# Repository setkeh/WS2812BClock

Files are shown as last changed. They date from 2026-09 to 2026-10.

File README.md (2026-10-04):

# WS2812BClock

A wall clock built from 88 addressable SK6812 pixels driven by an ESP32: a
60-pixel ring showing hour, minute and second hands, and a four-digit
seven-segment display showing the time and date. Time comes from NTP, and
firmware updates arrive over HTTPS from a private update server.

Hardware geometry, the LED pinout and the printable soldering jigs live in
[`CAD/README.md`](CAD/README.md).

## Setting up on a new machine

Everything except three local secrets is in the repo.

### 1. Toolchain

The Nix flake pins ESP-IDF v5.5.2 and every toolchain:

```bash
direnv allow          # or: nix develop
idf.py --version      # ESP-IDF v5.5.2
```

For VS Code, install the **ESP-IDF** and **direnv** extensions. The flake
registers itself with the ESP-IDF extension automatically (see the shell hook
in `flake.nix`), so no manual "configure extension" step is needed.

### 2. The three things that are *not* in the repo

`sdkconfig` is gitignored, so each machine needs these set once:

| What | Where | Notes |
| --- | --- | --- |
| WiFi SSID and password | `idf.py menuconfig` → *WS2812B Clock Wifi* | Never put these in `sdkconfig.defaults` — that file is committed. |
| OTA server token | *WS2812B Clock OTA* → `OTA_AUTH_TOKEN` | Same reasoning. |
| Update server root CA | `components/ota/certs/server_ca.pem` | Copy the CA root there. `*.pem` is gitignored. |

Everything else has a sensible default in `sdkconfig.defaults` (4 MB flash, OTA
partition table, rollback, display pins and brightness, timezone).

### 3. Signing key

Images are signed, so **every build needs the key**. It lives in 1Password and
is fetched to tmpfs only for the duration of a build — see *Signing* below.

### 4. First flash

The partition table has two OTA slots, so a board coming from an older layout
must be erased once:

```bash
idf.py -p /dev/ttyUSB1 erase-flash
idf.py -p /dev/ttyUSB1 flash monitor
```

Afterwards, plain `flash` is enough.

## Configuration reference

All under `idf.py menuconfig`:

| Menu | Options |
| --- | --- |
| *WS2812B Clock Display* | Ring and digit GPIOs and pixel counts, day/night brightness for each, night window (default 19:00–06:00), rotation and `DISPLAY_CYCLE_SECONDS` |
| *WS2812B Clock Environment Sensor* | `DHT_ENABLE`, data GPIO, reading interval, retries |
| *WS2812B Clock Wifi* | SSID, password, `WIFI_MAXIMUM_RETRY`, `WIFI_POWER_SAVE` (off: modem sleep costs OTA throughput and log latency for power a mains-powered clock does not need) |
| *WS2812B Clock NTP* | Server (default `pool.ntp.org`), timezone (default Sydney), sync method |
| *WS2812B Clock OTA* | Base URL, model directory, token, certificate source, check-at-boot and interval, `OTA_PROGRESS_STEP_PCT`, `OTA_UPLOAD_COREDUMP`, `OTA_CRASH_URL` |
| *WS2812B Clock Remote Logging* | Collector host and UDP port, syslog APP-NAME, line length, queue depth, core dump reporting |
| *WS2812B Clock Debugger* | `DEBUG_BUILD` logging, status LED pin |
| *WS2812B Clock Fans* | Fan PWM pin |

Shipped defaults: ring on GPIO32 (60 px) at 5% day / 1% night, digits on
GPIO25 (28 px) at 50% day / 5% night. Brightness is worth tuning per build
once the diffusers are in — the values in a local `sdkconfig` win over these.

### Device identity

One value names the device, and everything follows it:

```
CONFIG_LWIP_LOCAL_HOSTNAME="hallway-clock"
```

It is not under any of this project's own menus — it lives in menuconfig under
**Component config → LWIP → Local netif hostname**, and defaults to
`espressif`, which is worth changing before a second device exists.

That one setting becomes the DHCP name on the network, the `host` label in
Loki, and the name a crash dump is filed under on the server. Nothing else
sets it: `logship` and the crash upload both read it back from the station
interface through `wifi_hostname()`, so they cannot disagree.

The distinction matters once there is more than one device, and it follows
RFC 5424:

| Field | Means | Set by | Example |
| --- | --- | --- | --- |
| HOSTNAME | which **device** | `CONFIG_LWIP_LOCAL_HOSTNAME` | `hallway-clock` |
| APP-NAME | which **firmware** | `CONFIG_LOGSHIP_APP_NAME` | `ws2812bclock` |

So every clock running this firmware shares an APP-NAME and has its own
HOSTNAME. `{app="ws2812bclock"}` selects the fleet; `{host="hallway-clock"}`
selects one of them. The same shape works for any other device built on this
pattern.

### Site-specific settings and backing them up

Three things are not in this repository and never should be: the WiFi
credentials, the OTA token, and the update server's root CA. The first two, plus
the update server and log collector addresses, belong in
**`sdkconfig.defaults.local`** — gitignored, and the one file worth backing up.
Copy `sdkconfig.defaults.local.example` and fill it in.

```bash
cp sdkconfig.defaults.local.example sdkconfig.defaults.local
$EDITOR sdkconfig.defaults.local
```

`CMakeLists.txt` appends it to `SDKCONFIG_DEFAULTS` when it exists, so a fresh
clone configures itself. Note what that does and does not do: these are
*defaults*. An existing `sdkconfig` overrides them, so editing this file after
the fact changes nothing until `sdkconfig` is regenerated —
`rm sdkconfig && idf.py reconfigure`. What it buys you is that a lost or reset
`sdkconfig` costs one command instead of an evening of remembering what was in
which menu.

The firmware also complains at boot, at warning level, if it has no update
server or update checking is off — a clock that silently cannot update itself
looks perfectly healthy from across the room.

## Scripts

### `scripts/ota-key.sh` — signing key handling

```bash
./scripts/ota-key.sh fetch    # 1Password -> /run/user/$UID/ota_key.pem (tmpfs)
./scripts/ota-key.sh shred    # remove it again
```

The path must match `CONFIG_SECURE_BOOT_SIGNING_KEY`. Overridable with
`OTA_SIGNING_KEY` and `OTA_SIGNING_KEY_ITEM`.

VS Code runs these automatically: `idf.preBuildTask` fetches, `idf.postBuildTask`
and `idf.postFlashTask` shred. From a terminal, do it by hand:

```bash
./scripts/ota-key.sh fetch && idf.py build && ./scripts/ota-key.sh shred
```

A failed build skips the post task and leaves the key in tmpfs — RAM only,
owner-readable, gone on reboot, but `shred` cleans it up sooner.

**1Password on a fresh machine:** `op` must be the setgid wrapper, which on
NixOS comes from the system modules, not just the package:

```nix
programs._1password.enable = true;
programs._1password-gui = { enable = true; polkitPolicyOwners = [ "setkeh" ]; };
users.users.setkeh.extraGroups = [ "onepassword" "onepassword-cli" ];
```

Then enable *Settings → Developer → Integrate with 1Password CLI* in the app.
Without that, `op` fails with "connecting to desktop app"; setting
`OP_BIOMETRIC_UNLOCK_ENABLED=false` and using `op signin` is the fallback.

### `scripts/deploy-firmware.sh` — publish a release

```bash
./scripts/deploy-firmware.sh              # fetch key, build, publish, shred key
./scripts/deploy-firmware.sh --no-build   # publish the existing build
./scripts/deploy-firmware.sh --dry-run    # print the manifest, upload nothing
```

Version and model come from `sdkconfig`, so a release is: bump
`CONFIG_APP_PROJECT_VER` in menuconfig, run the script. It uploads to
`$OTA_HOST:$OTA_ROOT/<model>/` (default `ota:/srv/ota`), image first and
`latest.json` second, so devices never see a manifest pointing at a missing
file.

## OTA

### How a clock updates itself

1. After boot, once WiFi is up and NTP has synced, the running image marks
   itself valid — which cancels the rollback the bootloader would otherwise
   perform on the next reset.
2. If `OTA_CHECK_ON_BOOT` is set, it fetches `<base>/<model>/latest.json`.
3. If `version` there **differs** from the running version, it downloads the
   named file and reboots into it. Differing in either direction means a
   manifest edit can also roll a fleet *back*.
4. `esp_https_ota` verifies the image signature during install, so an unsigned
   or corrupted download is rejected before it can boot.

### Server layout

```
/srv/ota/ws2812bclock-esp32/
├── latest.json                        {"version","file","sha256","size"}
├── ws2812bclock-esp32-0.1.0.bin
└── ws2812bclock-esp32-0.2.0.bin
```

The model directory names the hardware *and* the chip target, so a build for
one target can never be served to another.

### Certificates

`OTA_CERT_SOURCE` picks how the server is verified:

- **Public CA** — uses the ESP-IDF certificate bundle. For a publicly trusted
  certificate.
- **Embedded certificate** — trusts only `components/ota/certs/server_ca.pem`,
  compiled into the firmware. This is the private-CA path.

Embed the **root**, not the leaf or intermediate: server certificates can then
be reissued without reflashing. The server must serve the full chain
(leaf + intermediate), because the device only holds the root.

The device needs working DNS for the server's name and a reachable NTP server —
TLS validation fails if the clock's time is wrong, and short-lived certificates
make that stricter.

### Signing

Signing uses `SECURE_SIGNED_APPS_NO_SECURE_BOOT`, which verifies image
signatures **without** burning eFuses, so a mistake cannot brick a board.

The scheme is **ECDSA (NIST P-256)**, because this ESP32 is a rev v1.0
D0WDQ6: RSA-3072 (secure boot v2) needs rev v3.0 or later. Newer chips
(S3, C6) support RSA-3072, so a move to that hardware means a new key and a
scheme change.

**The key must match the scheme**, or the build fails at the signing step with
"Incorrect ECDSA private key specified":

```bash
# this hardware (secure boot v1 scheme)
espsecure.py generate_signing_key --version 1 --scheme ecdsa256 key.pem

# future S3/C6 hardware (secure boot v2)
espsecure.py generate_signing_key --version 2 --scheme rsa3072 key.pem
```

Store each in 1Password as its own document and point `OTA_SIGNING_KEY_ITEM`
at the one matching the target.

Losing the signing key means signed clocks stop accepting updates and must be
reflashed over USB. It lives in 1Password; keep that recoverable.

## The centre display

The two plates rotate through four readings, ten seconds each by default
(`DISPLAY_CYCLE_SECONDS`):

| Phase | Shows | Example |
| --- | --- | --- |
| Time | `HH MM` | `18 19` |
| Date | `DD MM` | `01 10` |
| Temperature | `NN °C` | `21 °C` |
| Humidity | `NN rH` | `47 rH` |

With no sensor fitted it rotates through time and date only.

The phase comes from seconds since midnight rather than `tm_sec`, so it does not
jump at the top of each minute. At the default ten seconds the full cycle is 40
seconds and 86400 divides exactly by that, so midnight passes without a step
either. Other values work, they just stutter once a day.

A temperature or humidity the sensor has not supplied shows as dashes rather
than a stale number. A sensor that has stopped answering should be visible on
the clock face, not quietly skipped.

## Environment sensor

A DHT11 on a single data line, read every `DHT_INTERVAL_S` seconds (default 30).
The part is specified to 1 °C and 1 % and updates about once a second at best,
so there is nothing to gain from reading it more often.

**The pin must be output capable.** The protocol is bidirectional on one wire:
the host pulls the line low for about 20 ms to request a reading, then releases
it and listens. **GPIO34–39 cannot be used** — they are input only on the ESP32,
which is why `DHT_GPIO` stops at 33. The line idles high and needs an external
4.7–10 kΩ pull-up to the sensor's supply; the internal pull-up is enabled as a
backstop so a missing resistor shows up as flaky readings rather than silence.

Keep its wire away from the two LED data runs.

### Why it does not disable interrupts

The timing is tight — a bit is a 50 µs low followed by roughly 27 µs of high for
a zero or 70 µs for a one — and the usual way to read one of these is to mask
interrupts for the whole 4 ms exchange. That would be the wrong trade here: it
would disturb the RMT refills driving the LEDs and upset WiFi, and this build
has had quite enough trouble with marginal LED timing already.

Instead the driver times with `esp_timer_get_time()` and leaves interrupts
alone. A read that gets preempted mid-bit fails the sensor's own checksum and is
retried. At one reading every thirty seconds, retries are free, and the result
is self-correcting rather than timing-fragile.

## Remote logging

A clock on a wall has no serial cable, so every log line is also copied to a
syslog collector over UDP. Set the collector in `idf.py menuconfig` →
*WS2812B Clock Remote Logging*; with no host configured the component does
nothing and costs nothing.

```
CONFIG_LOGSHIP_HOST="logs.example.lan"
CONFIG_LOGSHIP_PORT=5514
```

The device sends **RFC 5424** frames, one datagram per line, facility `local0`,
severity taken from the ESP-IDF level letter. Before the first NTP sync the
timestamp field is `-`, which tells the collector to stamp the line on arrival
rather than filing boot messages in 1970. HOSTNAME is the device and APP-NAME
is the firmware — see *Device identity* below.

Watch the stream with nothing but netcat, before any collector exists:

```bash
nc -ul 5514
```

Frames end in a newline (RFC 6587 non-transparent framing). Receivers choose
their parser from the first byte — `<` means newline-delimited — and then treat
the datagrams from one sender as a single stream, so the terminator is what
keeps consecutive messages apart.

Any syslog receiver works. As an example, a promtail scrape config:

```yaml
scrape_configs:
  - job_name: ws2812bclock
    syslog:
      listen_address: 0.0.0.0:5514
      listen_protocol: udp          # defaults to tcp
      use_incoming_timestamp: true
      labels:
        job: ws2812bclock
    relabel_configs:
      - source_labels: [__syslog_message_hostname]
        target_label: host
      - source_labels: [__syslog_message_severity]
        target_label: level
      - source_labels: [__syslog_message_app_name]
        target_label: app
```

The relabelling is not optional, whichever receiver you use: both promtail and
Alloy drop every `__`-prefixed label, so without it the logs arrive with no
hostname and no severity and one clock cannot be told from another. Alloy's
`loki.source.syslog` takes the same settings under different names — `address`
and `protocol` rather than `listen_address` and `listen_protocol` — and moves
relabelling to a `relabel_rules` attribute, so the config is not a
transliteration.

### What it costs, and what it drops

The log hook runs on whichever task called `ESP_LOGx`, so it never sends
anything itself: it formats the line, copies it into a queue and returns. A
sender task does the network work. If the collector is unreachable the lines
stay queued — so the boot messages survive the wait for WiFi — and once the
queue is full the newest lines are dropped and counted, with the count sent
once the link comes back. The clock never blocks or stalls because logging
cannot get out.

The queue is the only real cost: `LOGSHIP_QUEUE_DEPTH` x `LOGSHIP_LINE_MAX`
from the heap (about 6 KB at the defaults) plus a 4 KB sender task.

Volume is controlled by `DEBUG_BUILD`, which is what it is for. With it set,
the tick loop logs once a second, which is far too much to ship. With it
clear, a working clock is nearly silent: a heartbeat every five minutes with
uptime and heap figures, plus whatever actually goes wrong.

## Core dumps

Panic output goes straight to the UART as the chip resets, so on a wall-mounted
clock it is lost. `esp_core_dump` writes a dump to the 64 KB `coredump`
partition instead, which survives the reset:

```bash
idf.py -p <port> coredump-info      # decode: panic reason, backtrace, all tasks
```

An empty partition decodes as version `0xffff` and size `4294967295` — that is
erased flash, not a failure.

Debug builds accept **`crash`** typed on the serial console, which calls
`abort()` on purpose so the path can be tested without waiting for a real
fault. The command lives in the UART receive task, which only exists when
`DEBUG_BUILD` is set, so a release build does not have it.

After a crash, the next boot logs the dump's summary — faulting task, program
counter, `EXCCAUSE`, and a backtrace — once the network is up, so it arrives at
the collector like any other log line and the clock never has to be unplugged
to find out what happened. Paste the backtrace into `addr2line` against the
matching build, which the report identifies by its app ELF SHA256.

With `OTA_UPLOAD_COREDUMP` set, the dump itself is then posted to the crash
receiver in `server/crashd` and erased once the server has taken it. Erasing
only on success makes it exactly-once: a clock that cannot reach the server
keeps its dump and retries on the next boot. Without it the dump stays in flash
and `idf.py coredump-info` over USB is the way to get a full trace.

### Symbols are published with every release

A core dump is undecodable without the exact ELF that produced it, and `build/`
is overwritten by the next build. `deploy-firmware.sh` therefore publishes
`<model>-<version>.elf.gz` alongside each image and names it in `latest.json`.
The crash report logs the crashing build's `app_elf_sha256`, so the report
identifies which one it needs — it just has to still exist.

To decode a dump against a release that is no longer in `build/`:

```bash
scp ota:/srv/ota/<model>/<model>-<version>.elf.gz .
gunzip <model>-<version>.elf.gz
esp-coredump info_corefile -c <dump> <model>-<version>.elf
```

The ELF is about ten times the size of the image it describes and compresses
roughly three to one, so releases cost a few megabytes each on the update
server. Old images and symbols are never cleaned up; that retention policy is
still to be decided.

## The crash receiver — `server/crashd`

### Why it exists

Everything else the clock says travels as syslog over UDP, which is lossy on
purpose: a clock must never stall because logging cannot get out. A core dump
cannot travel that way. It is a binary ELF of tens of kilobytes that has to
arrive byte-perfect, and a log store has nothing useful to do with it — you
cannot search or aggregate a core dump, and base64 in a text index would cost a
third more for nothing. So it needs its own path, and that path needs something
at the far end to catch it.

### Why not just let Caddy accept the upload

Caddy's standard build has no upload handler, so this would mean rebuilding it
with `xcaddy` and a WebDAV module. That was rejected deliberately.

The endpoint is reachable from the network the devices are on. Firmware
images are signed, so
nobody can install a malicious one — but **`latest.json` is not signed**, and
anything that can write to the firmware tree can pin the whole fleet to an old
version or simply fill the disk. Scoping a general-purpose write module
tightly enough to prevent that is more thinking than a service whose only
ability is to create one new file per request, under a name it chooses itself,
in a directory that is not the firmware one.

### How it operates

A single static Go binary. No dependencies, no database, no TLS of its own.

```
POST /crash/{model}
  X-OTA-Token         the same shared token the firmware sends for updates
  X-Device-Hostname   which clock
  X-Firmware-Version  what it was running
  X-App-Elf-Sha256    identifies the build whose symbols decode this dump
  body                the coredump partition, verbatim
```

It listens on localhost and sits behind the existing Caddy terminator, so
devices reach it on the same host, with the same certificate and token as
update checks — which also means it needs no firewall rule of its own.

Stored as `{dir}/{model}/{hostname}-{version}-{unix}.elf`. The server picks
that name; nothing a client sends reaches a filesystem path without matching
`^[A-Za-z0-9][A-Za-z0-9._-]{0,63}$` first. Uploads are written to a temporary
file and renamed, so a transfer that dies half way never looks like a complete
dump. The token is compared in constant time, and the body is capped at twice
the partition size.

On the device, the dump is streamed in 1 KB chunks from its own task, and
**erased only on a 2xx**. That makes the whole thing exactly-once and
self-limiting: a clock that cannot reach the server keeps its dump and tries
again on the next boot, and a crash loop uploads one dump per crash rather than
the same one repeatedly.

### Deploying it

Releases are built by `.github/workflows/release-crashd.yml` on a `crashd-v*`
tag — tagged separately from the firmware, which is versioned through
`CONFIG_APP_PROJECT_VER` rather than git tags — and attached as a static
`linux/amd64` binary with a `.sha256` beside it. The host needs no Go
toolchain.

It runs alongside the update server, deployed by whatever manages that host.
**This repository owns the code and the wire format; the infrastructure that
hosts it owns how it runs** — the service unit, the reverse proxy route,
directory ownership. The split is deliberate: the receiver's contract is the
firmware's, so those two change together, in one commit, here.

The one constraint that matters when deploying it: its storage directory must
not sit under the firmware tree, and the unit should have no write access to
`/srv/ota` at all. That is the whole reason it exists in this shape.

`server/crashd/README.md` has the full interface, flags and decode recipe.

## Layout

```
components/
├── display/   both LED chains, position maps, font, brightness
├── ntp/       SNTP, timezone, NTP_EVENT, ntp_time_is_valid()
├── wifi/      station mode, retries forever with back-off
├── ota/       manifest check, HTTPS update, rollback, crash dump upload
├── dht/       DHT11 temperature and humidity, sampled in the background
├── fan/       LEDC PWM fan control with kick-start
├── logship/   syslog-over-UDP log shipping, crash reports on boot
└── debug/     activity LED on serial traffic
main/          startup, the second-aligned tick loop, rendering
CAD/           jigs, clock geometry, KiCad project
scripts/       signing key and release helpers
server/crashd/ core dump receiver, deployed beside the OTA server
.github/       CI for server/crashd, and its tagged release build
```

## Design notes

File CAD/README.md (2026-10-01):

# CAD — clock face geometry, LED jigs, hardware notes

Mechanical reference for the WS2812BClock build: the numbers the firmware and any
future PCB depend on, plus the print-it-yourself jigs that hold the LEDs.

## Where the geometry comes from

The printed clock body is [Thingiverse thing 3966304](https://www.thingiverse.com/thing:3966304)
("ESP8266 Clock and Thermometer" by **kwg08**, licensed **CC BY-SA**). Every dimension
below was measured directly from its STLs (`led_clock_quarter_face.stl`, `center.stl`),
not taken from the listing.

**Those STLs are not redistributed here** — download them from the link above. The
measurements recorded in this file are all the firmware and the jigs need.

That design was drawn for 8 mm round through-hole pixels. We use **SK6812 5050 SMD**
parts instead, which is why the jigs exist: they centre a 5×5 mm part in a Ø12 mm seat.

## Clock face — outer ring

| Feature | Value |
| --- | --- |
| LED seats | **60**, at **radius 160.0 mm**, one every **6°** |
| Centre-to-centre spacing | 16.75 mm chord (≈11.3 mm gap between LED bodies) |
| Seat | Ø12 mm round, 3 mm deep, opening from the back |
| Front aperture | Ø8.4 mm through-hole |
| Hour marker holes | 12 × Ø4 mm at radius 131.0 mm, every 30° |
| Screw holes | 6 × Ø3.6 mm at radius 93.3 mm (matches `center.stl`) |

## Centre plate — seven-segment digits

**28 LEDs: 4 digits × 7 segments, one LED per segment.** Same Ø12 mm round seats, 3 mm
deep, each behind a segment-shaped slot in the front face.

Digit centres: **x = −52, −20, 21, 53** (y = 0 is the middle segment row).

Segment offsets from a digit centre (mm):

| Segment | Offset |
| --- | --- |
| top | (0, +20.00) |
| top-left | (−10, +9.93) |
| top-right | (+10, +9.93) |
| middle | (0, −0.13) |
| bottom-left | (−10, −10.07) |
| bottom-right | (+10, −10.07) |
| bottom | (0, −20.00) |

**Total pixel count: 60 + 28 = 88.**

## LED part: SK6812 5050 RGB

Per the [Normand SK6812 datasheet Rev 06](https://www.normandled.com/upload/201603/SK6812%20LED%20%20Datasheet.pdf):

| Pin | Symbol | Note |
| --- | --- | --- |
| 1 | VDD | diagonally opposite VSS |
| 2 | DOUT | diagonally opposite DIN |
| 3 | VSS | **the chamfered corner**, viewed from the lens side |
| 4 | DIN | shares the short edge with VSS |

- Supply **3.5–5.5 V**. Reverse polarity destroys the part in seconds — it gets hot and
  never lights.
- Logic threshold **VIH = 0.7 × VDD**, so 3.5 V at a 5 V supply. The ESP32's 3.3 V output
  is below that; a plain silicon diode in the LED's +5 V feed (≈4.3 V rail, ≈3.0 V
  threshold) fixes it if a chain proves unreliable.
- 24-bit data, **GRB** order, MSB first. Driver config: `LED_MODEL_SK6812` with
  `LED_STRIP_COLOR_COMPONENT_FMT_GRB`.
- **Lens-down in the jig mirrors the pinout.** Identify VSS on a scrap part with a meter
  on diode test (VSS conducts to all three others), mark that jig corner, and orient every
  LED to match.

### Pad mapping that was verified on these parts (2026-09-25)

Established empirically on the eBay SK6812 5050s used in this build, after two LEDs lit:

> **DIN is the pad next to VDD. DOUT is the pad next to VSS.**
> VDD is diagonally opposite VSS, and DIN diagonally opposite DOUT.

Both data pads are adjacent to VSS — one along each axis — so "next to VSS" is ambiguous
and is not a safe rule. Key off VDD instead.

Diagnostics that identified the faults, for reuse on the remaining pixels:

- **Data line sits at ~2.2 V instead of 3.3 V** (measured through the 390 Ω series
  resistor, ≈2.8 mA): the LED is not powered, and the data pin is phantom-powering the
  chip through its protection diode. Check VDD/VSS at the LED's own pads.
- **No light, no heat, correct supply:** data on the wrong pad (DOUT instead of DIN).
- **Hot, no light:** VDD/VSS reversed. The part is destroyed within seconds.
- **DOUT is idle unless more pixels' data is being sent than the chain has consumed.**
  Testing with `LED_TEST_COUNT` set to 1 means LED 1 absorbs the whole frame and forwards
  nothing, so probing DOUT proves nothing. Set the count to at least the number wired.
- A plain 1 Hz GPIO toggle on the data pin (meter-readable) separates "pin/board/firmware"
  faults from LED-side faults; the LED never repeats it, since it isn't valid data.

## Jigs

Both parts hold LEDs **lens-down** so the pads face up for soldering, and with
`mount_bosses = true` they stay in the clock as the LED mounting plate: the Ø11.6 mm
spigots plug into the Ø12 mm seats and centre each pixel over its aperture.

| File | Covers | Printed size |
| --- | --- | --- |
| `led_ring_jig.scad` → `led_ring_jig_seg.stl` | 6 ring LEDs (36°); 10 make the ring | 26 × 113 × 5.8 mm |
| `led_seg_jig.scad` → `led_seg_jig_{left,right}.stl` | 14 digit LEDs each (2 digits) | 70 × 57.5 × 5.8 mm |

Key parameters (top of each file): `positions`, `ring_radius`, `led_count`,
`fit_clearance` (0.25 mm per side, loosen/tighten to suit the printer), `recess_depth`
(1.2 mm of the 1.6 mm body, so pads stand proud), `light_hole` / `relief_dia` (4.6 mm),
`boss_dia` (11.6 mm), `mount_bosses`.

Printed in **PLA** on an Ender 3 V2 Neo, ~1 h per ring segment. PLA softens around 60 °C,
so keep the iron at 280–300 °C and each joint to 1–2 s; PETG would have more margin.

## Wiring plan

- **10 ring segments of 6 LEDs**, each with its own 5 V/GND feed from the regulator
  (18 AWG trunk), so only the **data line is continuous** around the ring.
- Run a **ground wire alongside the data** across each segment joint. The data return
  path is ground; without a local link the return loop goes back to the star point and
  the signal edges suffer.
- **30 AWG wire-wrap wire** for LED-to-LED links and data: ~0.33 Ω/m, so a 12 mm link is
  ~0.004 Ω, negligible at the ≤360 mA a full-white segment draws.
- **Decoupling per power group** (not per LED): 100 nF ceramic + 100 µF electrolytic
  across 5 V/GND at each feed point, ceramic closest to the LEDs. 10 groups on the ring,
  2–4 on the digits. 1000 µF bulk at the regulator.
- Full-white current for 88 pixels is ~5 A; cap brightness in firmware (25 % ≈ 1.3 A).

## Data line level: the diodes on the power feeds

The SK6812 needs a logic high of at least **0.7 x VDD**. The regulator measures
**5.04 V**, which puts the threshold at **3.53 V**, and the ESP32 drives **3.3 V**.
The data line is therefore below specification on this build, and has behaved
accordingly: intermittent wrong-coloured pixels on both chains, and on 2026-10-01 the
seven-segment chain latched a corrupted frame and stopped accepting data entirely
until power was removed for a minute. Firmware was ruled out — all 28 segment pixels
are rewritten every second — and so was a broken connection, since a power cycle
restored it without anything being touched. See issue #36.

The fix on this hand-wired build is a **1N4007 in series with each of the twelve 5 V
injection points**, dropping the LED supply to roughly 4.0–4.3 V:

| Load | LED VDD | Threshold (0.7 x VDD) | ESP32 drives |
| --- | --- | --- | --- |
| Low (normal brightness) | ~4.34 V | 3.04 V | 3.3 V |
| Heavy (bright effects) | ~4.04 V | 2.83 V | 3.3 V |

The margin improves under load, because a diode's forward drop rises with current.
Both figures stay inside the SK6812's 3.5–5.5 V supply range.

All twelve feeds get a diode rather than one, so brightness stays uniform across the
ring and digits; the overall loss is retuned with the brightness percentages in
menuconfig. A single diode on the first LED's VDD alone would also work — that LED
then outputs ~4.3 V, satisfying every LED after it — but it leaves one pixel visibly
dimmer, which on a seven-segment digit is one dim segment.

**A lower-drop diode is the wrong instinct here.** A Schottky at ~0.4 V leaves VDD at
~4.64 V and the threshold at 3.25 V, which is almost exactly what the ESP32 drives and
no better than the present situation. Two diodes in series overshoot the other way:
~3.6 V supply is only 0.1 V above the minimum. Around 0.7–1.0 V of drop is the useful
range, which is what an ordinary silicon rectifier gives.

Worth measuring once fitted: the supply at the LED furthest from an injection point
during a full-white test, confirming it stays above 3.5 V, and the diode temperature
during a bright animation, since current does not divide evenly between twelve feeds.

## If this gets rebuilt

A custom PCB ring at the same R160 / 6° geometry would replace both the jig and the
hand-wiring, with solderable pads, a ground plane and proper per-pixel decoupling.
It should also carry a **74AHCT125 or 74HCT245 level shifter** on the data lines,
which is the correct fix for the threshold problem above and makes the twelve diodes
unnecessary. It must be an AHCT or HCT part: an HC part needs 3.5 V for a logic high
on a 5 V supply and would change nothing.
The coordinates above drive it directly — KiCad's Python console can place the 88
footprints from the same angles and offsets rather than positioning them by hand.

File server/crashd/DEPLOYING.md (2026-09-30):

# Deploying crashd

What the service needs from whatever runs it. The deployment itself — the
service manager unit, the reverse proxy route, directory ownership — belongs
with the infrastructure that hosts it. This file states the requirements that
deployment has to satisfy.

## Artifact

Built by `.github/workflows/release-crashd.yml` on a `crashd-v*` tag and
attached to the release as `crashd-linux-amd64`, static (`CGO_ENABLED=0`), with
a `.sha256` beside it. The host needs no Go toolchain.

Tagged separately from the firmware, which is versioned through
`CONFIG_APP_PROJECT_VER` rather than git tags.

## Invocation

```
crashd -addr 127.0.0.1:8099 \
       -dir /srv/crash \
       -token-file /etc/crashd/token \
       -max-bytes 131072
```

`CRASHD_ADDR`, `CRASHD_DIR` and `CRASHD_TOKEN_FILE` are equivalent environment
variables. There is no default token and the service refuses to start without
one.

## Requirements

**Bind to loopback.** It speaks plain HTTP and knows nothing about
certificates. It goes behind the same TLS terminator that already serves the
update endpoint, so devices reach it on a host and certificate they already
trust.

**Run it unprivileged.** It needs write access to the storage directory and
read access to the token file. Nothing else.

**The storage directory must not sit inside the firmware tree, and the service
must have no write access to that tree.** This is the constraint the whole
design exists to satisfy. The endpoint is reachable from the network the
devices are on. Firmware images are signed, so a bad image cannot be installed
— but `latest.json` is not signed, and anything able to write to the firmware
directory can pin every device to an old version or fill the disk. That is why
this is a service that can only create one new file per request, under a name
it chooses itself, rather than a general-purpose upload module.

With systemd, `ProtectSystem=strict` and `ReadWritePaths=<storage dir>` express
this well.

**Token.** The same shared secret the firmware sends as `X-OTA-Token` for
update checks. The file should be mode 0400 and owned by the service user.

**Logging** goes to stdout, so whatever collects the service manager's journal
picks it up. One line per stored dump, including its size and the
`app_elf_sha256` identifying which build's symbols decode it.

## Reverse proxy

Route `/crash/*` to the listen address. With Caddy:

```
reverse_proxy /crash/* 127.0.0.1:8099
```

No authentication is needed at that layer — crashd compares the token itself,
in constant time. Checking it at the proxy as well is harmless, but the header
must still reach the backend.

`GET /healthz` returns `ok` and needs no token, which makes it a reasonable
health check.

## Network

If it sits behind the same terminator, on the same host and port the devices
already use for updates, no new firewall rule is needed. Anywhere else needs
the equivalent of the rule that lets devices reach the update endpoint.

## Sizing

A dump is at most 64 KB — the size of the coredump partition — and one is
produced only when a device actually crashes. The default 128 KB cap is twice
the partition; anything larger is not a dump.

Nothing prunes the storage directory. Retention is a decision for whoever
operates it.

## Enabling the token, in the right order

The firmware only sends `X-OTA-Token` when `CONFIG_OTA_AUTH_TOKEN` is
non-empty. crashd always requires it.

The two endpoints are not equally risky, and separating them makes this safe:

- **crashd can require the token from the moment it is deployed.** Nothing
  depends on the upload path yet, so there is no existing behaviour to break.
- **The update endpoint is the one to be careful with.** Publish firmware that
  sends the token and confirm every device is running it *before* requiring it
  there. Doing it the other way round means devices can no longer fetch
  updates, and recovering from that needs physical access to each one.

For more than one device, "every device" is the operative part: a single clock
still on an older build is one that has to be taken off the wall. The device's
own logs are the check — each reports its version at boot.

If enforcement does go wrong, removing it at the proxy restores updates
immediately and without touching any device, so that is the rollback.

A consequence worth recording: once the token is required, any machine that
builds firmware needs it, or the devices it builds cannot update themselves.
It belongs with the signing key, not in a tracked file.

## Verifying a deployment

```bash
# expected: 403
curl -X POST -H 'X-OTA-Token: wrong' --data-binary 'x' \
     https://<host>/crash/<model>

# expected: 201, and a file on disk
curl -X POST -H "X-OTA-Token: $TOKEN" \
     -H 'X-Device-Hostname: testhost' -H 'X-Firmware-Version: 0.0.0' \
     --data-binary 'not-a-real-dump' \
     https://<host>/crash/<model>
```

The second returns
`{"stored":"<model>/testhost-0.0.0-<unix>.elf","bytes":15}` and leaves that
file behind; delete it afterwards.

Nothing arrives from a real device until `OTA_UPLOAD_COREDUMP` is enabled in
the firmware with `OTA_CRASH_URL` pointing at this endpoint.

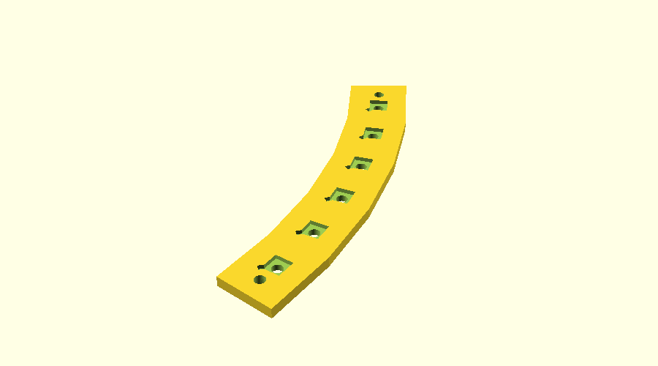
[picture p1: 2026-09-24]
CAD/led_ring_jig_preview.png

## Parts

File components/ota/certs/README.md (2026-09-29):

# OTA server certificate

Only needed when `OTA_CERT_SOURCE_EMBEDDED` is selected in menuconfig.

Put the PEM the device should trust here as `server_ca.pem`. Prefer your own
**CA** certificate over the server's own cert: server certs can then be
reissued without reflashing every clock, which matters because a device that
cannot trust the server cannot receive the update that would fix it.

The file is gitignored — it is deployment-specific, not project source.

    # one-off CA, long expiry
    openssl req -x509 -newkey rsa:4096 -keyout ca.key -out server_ca.pem \
        -days 3650 -nodes -subj "/CN=WS2812BClock OTA CA"

The server certificate must be issued by that CA, and its CN/SAN must match
the host in `OTA_UPDATE_URL`.

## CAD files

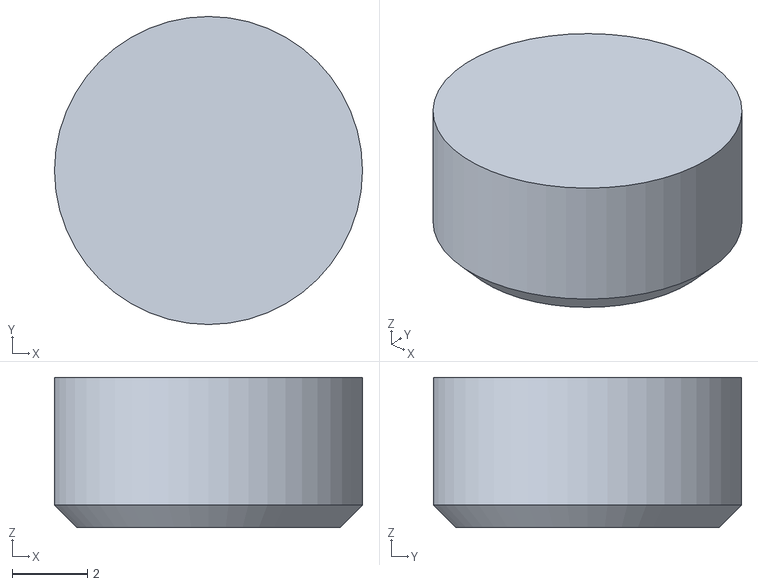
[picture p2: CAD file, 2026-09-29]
CAD/ring_diffuser_single.stl
8.20 x 8.20 x 4.00

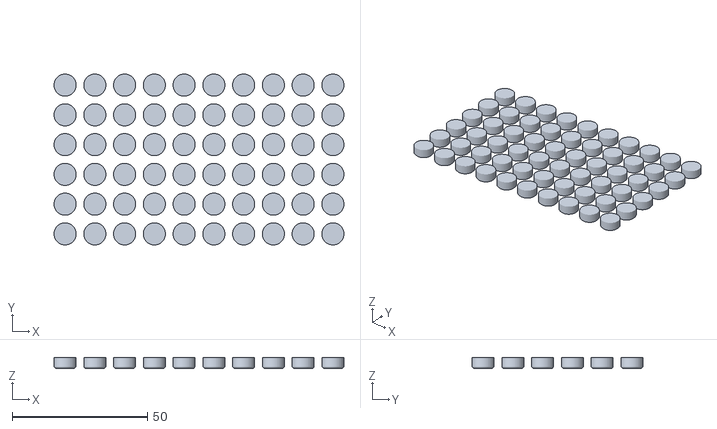
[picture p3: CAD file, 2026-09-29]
CAD/ring_diffuser_batch.stl
107.2 x 63.2 x 4.00

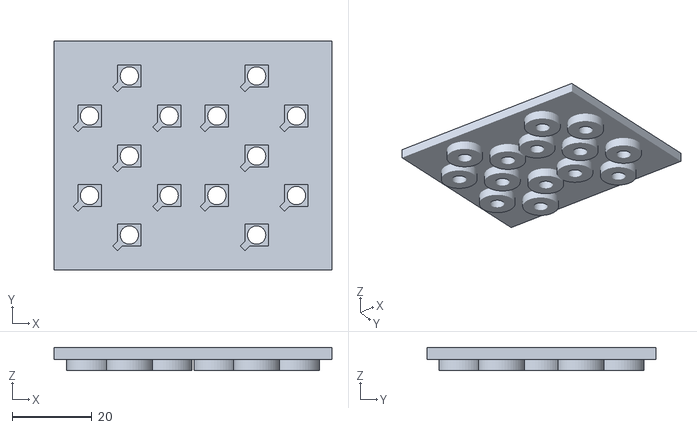
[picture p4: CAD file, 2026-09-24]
CAD/led_seg_jig_right.stl
69.9 x 57.5 x 5.80

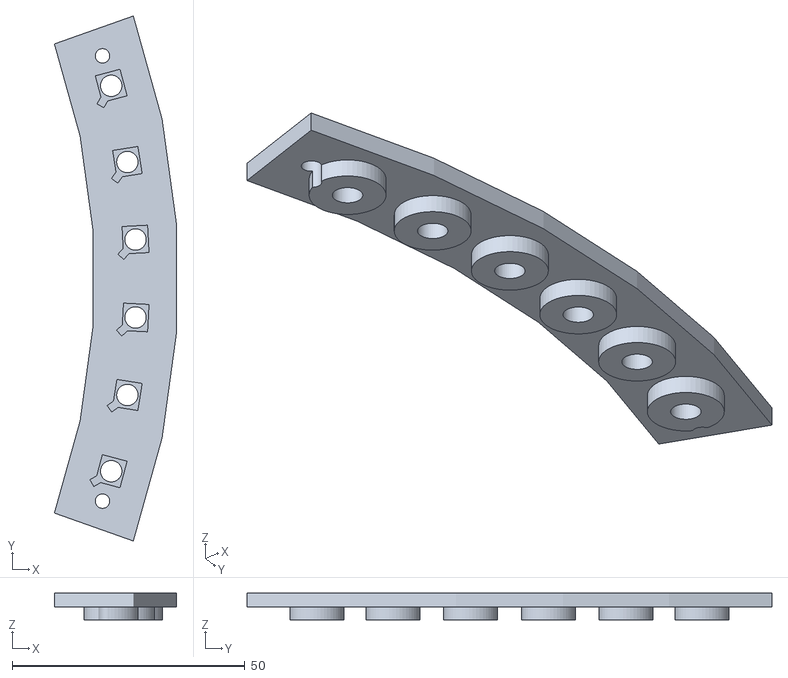
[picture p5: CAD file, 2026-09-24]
CAD/led_ring_jig_seg.stl
26.3 x 112.8 x 5.80

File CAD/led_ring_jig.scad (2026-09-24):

// Soldering jig for SK6812 5050 LEDs — WS2812BClock face ring
//
// Geometry taken from led_clock_quarter_face.stl:
//   60 LED pockets at radius 160.0 mm, one every 6 deg
//   chord spacing between pocket centres = 2*160*sin(3 deg) = 16.75 mm
//
// LEDs sit LENS DOWN in the recesses, so the solder pads face up.
// Solder the chain in the jig, then lift the finished arc out and drop it
// into the clock face pockets.
//
// Printed in segments so each piece fits a small print bed.
// 6 positions per segment -> 10 segments for the full ring, each about
// 99 x 26 mm.

/* [Ring geometry] */
ring_radius      = 160.0;  // from the STL
led_count        = 60;     // pixels in the full ring
positions        = 6;      // LED positions per printed segment

/* [LED pocket] */
// SK6812 5050 body is 5.4 (pad-to-pad axis) x 5.0 x 1.6 mm.
// The 5.4 axis runs tangentially so DOUT of one faces DIN of the next.
led_tangential   = 5.4;
led_radial       = 5.0;
led_height       = 1.6;
fit_clearance    = 0.25;   // per side; loosen if prints come out tight
recess_depth     = 1.2;    // < led_height so the LED stands proud and pads clear

/* [Plate] */
mount_bosses     = true;   // Ø11.6 spigots that plug into the face's Ø12 seats,
                           // so the jig doubles as the LED mounting plate
boss_dia         = 11.6;
boss_height      = 2.8;    // seat depth in the face is 3 mm
plate_thickness  = 3.0;
plate_width      = 18.0;   // radial width of the arc
relief_dia       = 4.6;    // hole under each LED: passes light, still supports it
corner_notch     = 1.2;    // marks the VSS/chamfered corner = orientation key
end_pin_dia      = 3.1;    // alignment holes in the segment ends
$fn              = 48;

step  = 360 / led_count;
r_in  = ring_radius - plate_width / 2;
r_out = ring_radius + plate_width / 2;
span  = step * (positions - 1);

pad = step * 0.75;   // material either side of the end positions

module arc_plate() {
    // Arc centred on angle 0
    rotate([0, 0, -(span / 2 + pad)])
        rotate_extrude(angle = span + 2 * pad)
            translate([r_in, 0]) square([plate_width, plate_thickness]);
}

module led_recess() {
    w = led_tangential + 2 * fit_clearance;   // tangential
    d = led_radial + 2 * fit_clearance;       // radial
    translate([0, 0, plate_thickness - recess_depth])
        cube([d, w, recess_depth + 0.1], center = false);
}

module pocket(i) {
    a = i * step;
    rotate([0, 0, a]) {
        w = led_tangential + 2 * fit_clearance;
        d = led_radial + 2 * fit_clearance;
        // recess, centred on the ring radius
        translate([ring_radius - d / 2, -w / 2, 0]) led_recess();
        // light / push-out hole
        translate([ring_radius, 0, -boss_height - 1])
            cylinder(d = relief_dia, h = plate_thickness + boss_height + 2);
        // orientation key: notch at the corner that takes the LED's
        // chamfered (VSS) corner. Data flows towards increasing angle.
        translate([ring_radius - d / 2, -w / 2, plate_thickness - recess_depth])
            cylinder(d = corner_notch * 2, h = recess_depth + 0.1, $fn = 4);
    }
}

module bosses() {
    if (mount_bosses)
        for (i = [0 : positions - 1])
            rotate([0, 0, -span / 2 + i * step])
                translate([ring_radius, 0, -boss_height])
                    cylinder(d = boss_dia, h = boss_height + 0.01);
}

module segment() {
    difference() {
        union() { arc_plate(); bosses(); }
        for (i = [0 : positions - 1])
            rotate([0, 0, -span / 2]) pocket(i);
        // alignment pin holes in both end faces (use a 3 mm pin/filament
        // offcut to line neighbouring segments up on the bench)
        for (s = [-1, 1])
            rotate([0, 0, s * (span / 2 + step * 0.4)])
                translate([ring_radius, 0, -boss_height - 1])
                    cylinder(d = end_pin_dia, h = plate_thickness + boss_height + 2);
    }
}

segment();

// Uncomment to preview the whole ring:
// for (s = [0 : led_count / positions - 1])
//     rotate([0, 0, s * step * positions]) segment();

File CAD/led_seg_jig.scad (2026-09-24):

// Soldering jig / backing plate for the 4-digit seven-segment display
// WS2812BClock — geometry taken from center.stl
//
//   28 LED pockets (4 digits x 7 segments), each 12 x 12 mm, floor at z = 13
//   digit centres at x = -52, -20, 21, 53
//   segment offsets from the digit centre:
//       top        ( 0.0,  20.00)
//       top-left   (-10.0,  9.93)   top-right   (10.0,  9.93)
//       middle     ( 0.0,  -0.13)
//       bottom-left(-10.0,-10.07)   bottom-right(10.0,-10.07)
//       bottom     ( 0.0, -20.00)
//
// LEDs sit LENS DOWN in the recesses so the pads face up for soldering.
// With mount_bosses = true the same part doubles as the backing plate:
// each boss plugs into a 12 mm pocket in center.stl and centres the 5050
// over the light hole.

/* [What to render] */
part          = "left";   // "left" = digits 1-2, "right" = digits 3-4, "all" = one piece
mount_bosses  = true;     // false = flat jig only, true = also a mounting plate

/* [LED pocket] */
led_tangential = 5.4;     // pad-to-pad axis of the SK6812 5050
led_radial     = 5.0;
fit_clearance  = 0.25;    // per side
recess_depth   = 1.2;     // < 1.6 mm body height, so pads stand clear
light_hole     = 4.6;     // under each LED: passes light, supports the body

/* [Plate] */
plate_thickness = 3.0;
border          = 6.0;    // material around the outermost pockets
boss_dia        = 11.6;   // fits the Ø12 mm round LED seats in center.stl
boss_height     = 2.8;    // pocket depth is 3 mm
corner_notch    = 1.2;    // orientation key
pin_dia         = 3.1;    // alignment pins between left and right halves
$fn             = 48;

digit_x  = [-52, -20, 21, 53];
segments = [[0, 20.00], [-10, 9.93], [10, 9.93], [0, -0.13],
            [-10, -10.07], [10, -10.07], [0, -20.00]];

w = led_tangential + 2 * fit_clearance;
d = led_radial + 2 * fit_clearance;

function digits_for(p) = p == "left"  ? [0, 1]
                       : p == "right" ? [2, 3]
                       : [0, 1, 2, 3];

module led_cut(x, y) {
    // recess for the LED body
    translate([x - w / 2, y - d / 2, plate_thickness - recess_depth])
        cube([w, d, recess_depth + 0.1]);
    // light / push-out hole
    translate([x, y, -boss_height - 1])
        cylinder(d = light_hole, h = plate_thickness + boss_height + 2);
    // orientation key in one corner of the recess
    translate([x - w / 2, y - d / 2, plate_thickness - recess_depth])
        cylinder(d = corner_notch * 2, h = recess_depth + 0.1, $fn = 4);
}

module plate_body(ds) {
    xs = [for (i = ds) digit_x[i]];
    x0 = min(xs) - 10 - w / 2 - border;
    x1 = max(xs) + 10 + w / 2 + border;
    y0 = -20 - d / 2 - border;
    y1 =  20 + d / 2 + border;
    translate([x0, y0, 0]) cube([x1 - x0, y1 - y0, plate_thickness]);
}

module bosses(ds) {
    if (mount_bosses)
        for (i = ds, s = segments)
            translate([digit_x[i] + s[0], s[1], -boss_height])
                cylinder(d = boss_dia, h = boss_height + 0.01);
}

module jig(p) {
    ds = digits_for(p);
    difference() {
        union() {
            plate_body(ds);
            bosses(ds);
        }
        for (i = ds, s = segments)
            led_cut(digit_x[i] + s[0], s[1]);
        // alignment pin holes on the split line between the halves
        if (p != "all")
            for (yy = [-30, 30])
                translate([p == "left" ? 3 : -3, yy, -boss_height - 1])
                    cylinder(d = pin_dia, h = plate_thickness + boss_height + 2);
    }
}

jig(part);

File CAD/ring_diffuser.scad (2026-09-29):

// Diffuser plugs for the clock face ring holes
//
// Each ring position is a Ø8.4 mm hole through the face (about 6 mm deep)
// with the LED sitting in the Ø12 mm seat behind it. These plugs push into
// that hole from the FRONT and scatter the light, so the pixel reads as a
// glowing dot rather than a bare point source.
//
// Print in WHITE PLA, 0.2 mm layers, 100% infill, no supports.
// White PLA is a good diffuser at 2-3 mm; natural/clear is worse, black useless.

/* [Fit] */
hole_dia     = 8.4;    // measured from the face STL
clearance    = 0.2;    // per diameter; increase if they won't push in
plug_len     = 4.0;    // shorter than the 6 mm channel, so it sits recessed
lead_in      = 0.6;    // chamfer on the leading edge, makes them easy to start

/* [Batch] */
count        = 60;     // one per ring pixel
cols         = 10;     // layout on the bed
spacing      = 11.0;   // centre to centre

$fn = 48;

plug_dia = hole_dia - clearance;

module plug() {
    // Chamfered nose so it starts square in the hole, then a plain barrel.
    union() {
        cylinder(d1 = plug_dia - 2 * lead_in, d2 = plug_dia, h = lead_in);
        translate([0, 0, lead_in])
            cylinder(d = plug_dia, h = plug_len - lead_in);
    }
}

module batch() {
    rows = ceil(count / cols);
    for (i = [0 : count - 1])
        translate([(i % cols) * spacing, floor(i / cols) * spacing, 0])
            plug();
}

batch();

// Uncomment for a single test fit before committing to 60:
// plug();

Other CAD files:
CAD/led_seg_jig_left.stl

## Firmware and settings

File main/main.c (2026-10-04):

#include <inttypes.h>
#include <stdbool.h>

#include "freertos/FreeRTOS.h"
#include "freertos/task.h"
#include <time.h>
#include <sys/time.h>

#include "esp_log.h"
#include "esp_system.h"
#include "esp_timer.h"
#include "sdkconfig.h"
#include "debug.h"
#include "fan.h"
#include "wifi.h"
#include "ntp.h"
#include "display.h"
#include "ota.h"
#include "logship.h"
#include "dht.h"

#include "nvs_flash.h"

static const char *TAG = "clock";

// How often a healthy clock says so. Between these, a working clock is silent.
#define HEARTBEAT_MIN 5
static volatile bool s_realign = false;
static bool s_confirmed_healthy = false;

// Define Config Build
#ifdef CONFIG_DEBUG_BUILD
#define DEBUG_BUILD 1
#else
#define DEBUG_BUILD 0
#endif

// A clock that is fine says so every few minutes. The heap figures are what
// would show a slow leak, and a gap between beats shows a reboot nobody saw.
static void heartbeat(void)
{
    static int64_t next_us = 0;
    int64_t now = esp_timer_get_time();

    if (now < next_us) return;
    next_us = now + (int64_t)HEARTBEAT_MIN * 60 * 1000000;
    ESP_LOGI(TAG, "alive: up %llu s, free heap %" PRIu32 ", low water %" PRIu32,
             (unsigned long long)(now / 1000000),
             esp_get_free_heap_size(), esp_get_minimum_free_heap_size());
}

// Sleep until just after the next full second of the real clock
static void wait_for_next_second(void)
{
    struct timeval tv;
    gettimeofday(&tv, NULL);
    int ms_to_next = 1000 - (tv.tv_usec / 1000);
    // pdMS_TO_TICKS rounds down to whole 10 ms ticks, which could wake us a few ms
    // *before* the boundary (still showing the old second). +1 tick lands just after it.
    vTaskDelay(pdMS_TO_TICKS(ms_to_next) + 1);
}

static void on_ntp_synced(void *arg, esp_event_base_t base, int32_t id, void *data)
{
    const struct timeval *tv = data;
    struct tm local;
    char buf[40];
    localtime_r(&tv->tv_sec, &local);
    strftime(buf, sizeof(buf), "%Y-%m-%d %H:%M:%S %Z", &local);
    ESP_LOGI(TAG, "NTP synced: %s", buf);
    s_realign = true;
}


void app_main(void) {
    ota_log_running_version();


    if (DEBUG_BUILD)
    {
        activity_led_init();
    }

    esp_err_t ret = nvs_flash_init();
    if (ret == ESP_ERR_NVS_NO_FREE_PAGES || ret == ESP_ERR_NVS_NEW_VERSION_FOUND) {
      ESP_ERROR_CHECK(nvs_flash_erase());
      ret = nvs_flash_init();
    }
    ESP_ERROR_CHECK(ret);

    // Capturing starts before WiFi, so the connection attempt itself ends up in
    // the log stream. Sending cannot start until the TCP/IP stack exists, so
    // that half waits for logship_start() below.
    logship_init();

    ESP_ERROR_CHECK(display_init());
    display_show_waiting();

    // Samples in the background; the display reads whatever it last managed.
    dht_init();

    if (!wifi_init_sta()) {
        ESP_LOGW(TAG, "WiFi not up yet, will keep retrying in the background");
    }

    // Only now is lwip up. Resolving the collector's name before this point
    // asserts inside lwip, because its mailbox does not exist yet.
    logship_start();

    // After the sender exists, so a crash report from the last boot actually
    // gets off the device.
    logship_report_coredump();

    // Then ship the dump itself, if that is configured. Strictly after the
    // summary above: a successful upload erases the dump.
    ota_upload_coredump_async();

    ESP_ERROR_CHECK(esp_event_handler_register(NTP_EVENT, NTP_EVENT_SYNCED, on_ntp_synced, NULL));
 
    ntp_init();

    wait_for_next_second();
    TickType_t last_wake = xTaskGetTickCount();
    int waiting = 0;

    while (true) {
        if (ntp_time_is_valid()) {
            struct timeval tv;
            struct tm local;
            char buf[40];
            char zone[8];
            gettimeofday(&tv, NULL);
            localtime_r(&tv.tv_sec, &local);
            display_show_time(&local);
            if (!s_confirmed_healthy) {
                s_confirmed_healthy = true;
                ota_mark_current_app_valid();   // network, time and display all up
#if CONFIG_OTA_CHECK_ON_BOOT
                ota_check_async();              // own task: TLS needs more stack than main has
#endif
            }
            if (DEBUG_BUILD) {
                // Milliseconds show the tick staying aligned to the real
                // second. One line a second is far too much to ship, so this
                // is the sort of thing the debug flag exists to compile out.
                strftime(zone, sizeof(zone), "%Z", &local);
                strftime(buf, sizeof(buf), "%H:%M:%S", &local);
                ESP_LOGI(TAG, "tick %s.%03ld %s", buf, (long)(tv.tv_usec / 1000), zone);
            }
            heartbeat();
        } else {
            display_show_waiting();
            // A state, not an event: report it every 30 s, not every tick.
            if (waiting++ % 30 == 0)
                ESP_LOGW(TAG, "waiting for the first NTP sync");
        }

        if (s_realign) {
            s_realign = false;
            wait_for_next_second();            // sleep to the next boundary instead
            last_wake = xTaskGetTickCount();   // restart the fixed rhythm from there
        } else {
            xTaskDelayUntil(&last_wake, pdMS_TO_TICKS(1000));
        }
    }

    /*
    init_fan_pwm();
    
    if (DEBUG_BUILD)
    {
        ESP_LOGI(TAG, "Test: find start threshold");
    }
    for (int p = 0; p <= 100; p += 5) {          // rising: find start threshold
        if (DEBUG_BUILD)
        {
            ESP_LOGI(TAG, "Duty Cycle Rising Set to: %d", p);
        }
        fan_set(p);
        ESP_LOGI(TAG, "up %d%%", p);
        vTaskDelay(pdMS_TO_TICKS(3000));
    }

    if (DEBUG_BUILD)
    {
        ESP_LOGI(TAG, "Test: find stall threshold");
    }
    for (int p = 100; p >= 0; p -= 5) {          // falling: find stall threshold
        if (DEBUG_BUILD)
        {
            ESP_LOGI(TAG, "Duty Cycle Falling Set to: %d", p);
        }
        fan_set(p);
        ESP_LOGI(TAG, "down %d%%", p);
        vTaskDelay(pdMS_TO_TICKS(3000));
    }*/
}

// LED Blink Example code
/*void app_main(void)
{
    gpio_reset_pin(BLINK_GPIO);
    gpio_set_direction(BLINK_GPIO, GPIO_MODE_OUTPUT);

    bool led_on = false;
    while (true) {
        led_on = !led_on;
        ESP_LOGI(TAG, "LED %s", led_on ? "on" : "off");
        gpio_set_level(BLINK_GPIO, led_on);
        vTaskDelay(pdMS_TO_TICKS(CONFIG_BLINK_PERIOD_MS));
    }


    if (DEBUG_BUILD)
    {
        ESP_LOGI(TAG, "FAN Duty set to 0");
    }
}*/

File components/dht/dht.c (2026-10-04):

#include "dht.h"

#include "sdkconfig.h"

#if CONFIG_DHT_ENABLE

#include <stdatomic.h>
#include <stdint.h>

#include "driver/gpio.h"
#include "esp_log.h"
#include "esp_timer.h"
#include "freertos/FreeRTOS.h"
#include "freertos/task.h"

static const char *TAG = "dht";

#define DHT_GPIO  CONFIG_DHT_GPIO
#define BITS      40

// No phase of the exchange lasts longer than the 80 us response pulses, so
// anything beyond this means the sensor has stopped talking.
#define PHASE_TIMEOUT_US 200

// A data bit is a ~50 us low followed by a high: about 27 us for a zero and
// about 70 us for a one. Anything between the two separates them.
#define BIT_THRESHOLD_US 45

// The datasheet asks for a second of settling after power-up.
#define SETTLE_MS 1500

// Consecutive failed readings before the cached values stop being offered. At
// the default interval that is a couple of minutes of silence.
#define STALE_AFTER 5

#define TASK_STACK 2560

// Humidity and temperature are both 0-100 on a DHT11, so the pair packs into
// one atomic word and a reader can never catch a half-updated value.
// -1 means nothing trustworthy is held.
#define PACK(h, t)   (((h) << 8) | ((t) & 0xFF))
#define UNPACK_H(v)  (((v) >> 8) & 0xFF)
#define UNPACK_T(v)  ((v) & 0xFF)

static atomic_int s_reading = -1;

// Which phase of the exchange failed. They point at different faults, so the
// distinction is worth keeping: a line that never rises is a missing pull-up or
// a short, no response is an unpowered or miswired sensor, a truncated frame is
// a connection failing mid-read, and a complete frame failing its checksum is
// interference or preemption.
typedef enum {
    DHT_OK = 0,
    DHT_NO_RISE,
    DHT_NO_RESPONSE,
    DHT_NO_RESPONSE_HIGH,
    DHT_NO_FIRST_BIT,
    DHT_TRUNCATED,
    DHT_BAD_CHECKSUM,
} dht_status_t;

static const char *const STATUS_TEXT[] = {
    [DHT_OK]               = "ok",
    [DHT_NO_RISE]          = "line never rose after the start pulse (pull-up missing, or line shorted low)",
    [DHT_NO_RESPONSE]      = "no response (sensor unpowered, miswired, or not a DHT11)",
    [DHT_NO_RESPONSE_HIGH] = "response low began but never ended",
    [DHT_NO_FIRST_BIT]     = "response high began but no data followed",
    [DHT_TRUNCATED]        = "frame cut short mid-read",
    [DHT_BAD_CHECKSUM]     = "frame received but failed its checksum",
};

// Spin until the line reads `level`, returning how long that took. Returns -1
// if it never happened.
//
// Deliberately does not mask interrupts. A DHT11 exchange takes about 4 ms,
// and holding off interrupts for that long would disturb the RMT refills
// driving the LEDs and upset WiFi. A read preempted mid-bit simply fails its
// checksum and is retried, which costs nothing at this sampling rate.
static int wait_for(int level, int timeout_us)
{
    int64_t start = esp_timer_get_time();
    int64_t waited;

    while (gpio_get_level(DHT_GPIO) != level) {
        waited = esp_timer_get_time() - start;
        if (waited > timeout_us) return -1;
    }
    return (int)(esp_timer_get_time() - start);
}

static dht_status_t sample(int *temperature_c, int *humidity_pct)
{
    uint8_t data[5] = {0};

    // Request: hold the line down long enough for the sensor to notice (it
    // wants at least 18 ms), then let go and listen.
    gpio_set_direction(DHT_GPIO, GPIO_MODE_OUTPUT);
    gpio_set_level(DHT_GPIO, 0);
    vTaskDelay(pdMS_TO_TICKS(20));
    gpio_set_direction(DHT_GPIO, GPIO_MODE_INPUT);

    // Wait for the pull-up to actually raise the line before looking for the
    // reply. Without this the line is still low from the start pulse, the first
    // wait returns immediately having consumed nothing, and the sensor's 80 us
    // response high gets measured as data bit zero -- shifting the whole frame
    // by a bit and guaranteeing a checksum failure.
    if (wait_for(1, PHASE_TIMEOUT_US) < 0) return DHT_NO_RISE;

    // The sensor answers with 80 us low, then 80 us high. Stepping past both
    // leaves us at the start of the first bit's low period.
    if (wait_for(0, PHASE_TIMEOUT_US) < 0) return DHT_NO_RESPONSE;
    if (wait_for(1, PHASE_TIMEOUT_US) < 0) return DHT_NO_RESPONSE_HIGH;
    if (wait_for(0, PHASE_TIMEOUT_US) < 0) return DHT_NO_FIRST_BIT;

    for (int i = 0; i < BITS; i++) {
        if (wait_for(1, PHASE_TIMEOUT_US) < 0) return DHT_TRUNCATED;  // bit's high begins
        int high = wait_for(0, PHASE_TIMEOUT_US);                     // and how long it lasts
        if (high < 0) return DHT_TRUNCATED;

        data[i / 8] <<= 1;
        if (high > BIT_THRESHOLD_US) data[i / 8] |= 1;
    }

    // The sensor sends its own sum, which is what makes an interrupted read
    // detectable rather than silently wrong.
    if (((data[0] + data[1] + data[2] + data[3]) & 0xFF) != data[4]) return DHT_BAD_CHECKSUM;

    *humidity_pct = data[0];
    *temperature_c = data[2];
    return DHT_OK;
}

static void dht_task(void *arg)
{
    int failures = 0;
    bool was_failing = false;

    vTaskDelay(pdMS_TO_TICKS(SETTLE_MS));

    while (true) {
        int temperature = 0, humidity = 0;
        dht_status_t status = DHT_NO_RESPONSE;
        bool ok = false;

        for (int attempt = 0; attempt < CONFIG_DHT_RETRIES && !ok; attempt++) {
            if (attempt > 0) vTaskDelay(pdMS_TO_TICKS(2000));   // it needs a moment between reads
            status = sample(&temperature, &humidity);
            ok = (status == DHT_OK);
        }

        if (ok) {
            atomic_store(&s_reading, PACK(humidity, temperature));
            if (was_failing) {
                ESP_LOGI(TAG, "sensor responding again: %d C, %d%%", temperature, humidity);
                was_failing = false;
            }
            failures = 0;
        } else if (++failures == STALE_AFTER) {
            // Said once on the way down rather than every cycle, and the
            // cached values are dropped so nothing stale is displayed.
            atomic_store(&s_reading, -1);
            was_failing = true;
            ESP_LOGW(TAG, "GPIO%d: %s (%d attempts)",
                     DHT_GPIO, STATUS_TEXT[status], failures);
        }

        vTaskDelay(pdMS_TO_TICKS(CONFIG_DHT_INTERVAL_S * 1000));
    }
}
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

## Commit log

2026-09-21 Add fan PWM control and serial activity LED
2026-09-24 Add LED mounting jigs, clock geometry reference and KiCad project
    [AmbersClock.kicad_pcb, AmbersClock.kicad_sch, led_ring_jig.scad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]
2026-09-29 Record verified SK6812 pad mapping and add ring diffuser plugs
    [ring_diffuser.scad, ring_diffuser_batch.stl, ring_diffuser_single.stl]
2026-09-29 Add OTA updates with manifest, signing and rollback
    [partitions.csv]
2026-09-29 Add coredump partition and console crash command for testing
    [partitions.csv]
2026-09-30 Add syslog log shipping and crash reports over WiFi
    [main.c]
2026-09-30 Disable WiFi power save by default
2026-09-30 Add the core dump receiver and upload dumps from the device
2026-09-30 Resolve the device name from one source and fix syslog host/app
2026-10-01 Renaming the KiCad Project
    [Clock.kicad_pcb, Clock.kicad_sch]
2026-10-01 Document the data line level problem and the diode fix
2026-10-04 Add a DHT11 and rotate the centre display through four readings
    [Clock.kicad_sch]
2026-10-04 Fixing some minor changes in the schematic during troubleshooting
    [Clock.kicad_sch]
